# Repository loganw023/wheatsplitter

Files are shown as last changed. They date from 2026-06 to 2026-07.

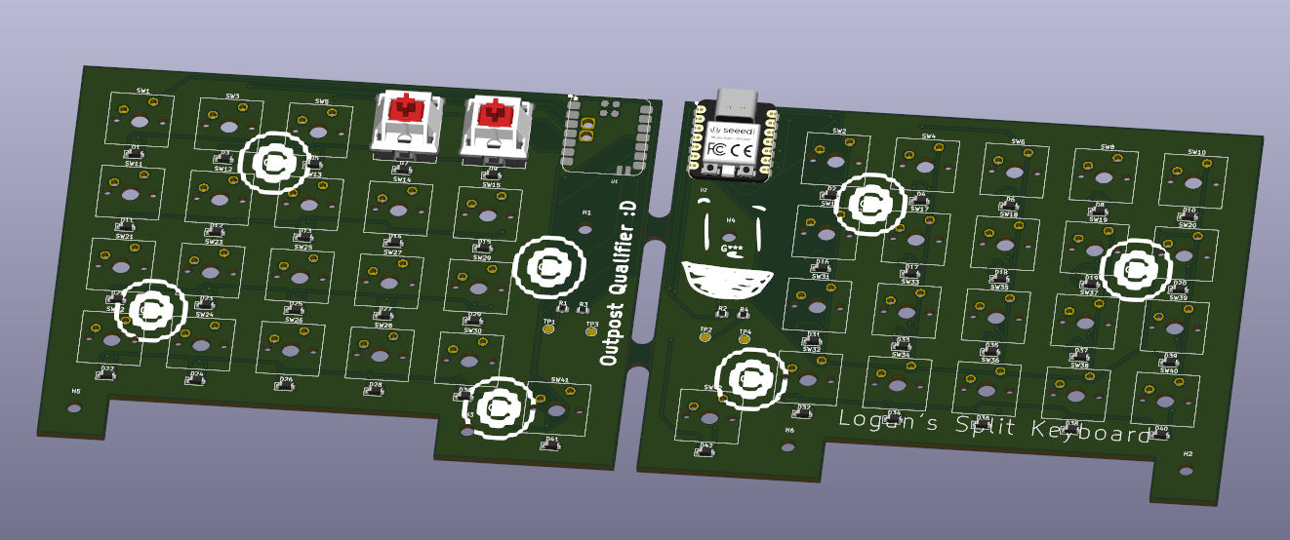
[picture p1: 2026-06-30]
Photos/Screenshot 2026-06-30 133020.png

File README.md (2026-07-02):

# wheatsplitter
This is a custom split ortholinear mechanical keyboard. I built this project to qualify for Outpost and to further my PCB, CAD, and coding skills. I was also interested in building this keyboard because I worked on Hackpad last summer, and wanted to continue building keyboard-type projects. This project taught me a lot about PCB design, especially since my last PCB was done in December. I also learned a lot about the specifics on how keyboard matrixes work, which was very interesting. 

## Schematic
Here is my schematic:


## PCB
Here is the PCB:



## CAD
Here is the CAD for the case:



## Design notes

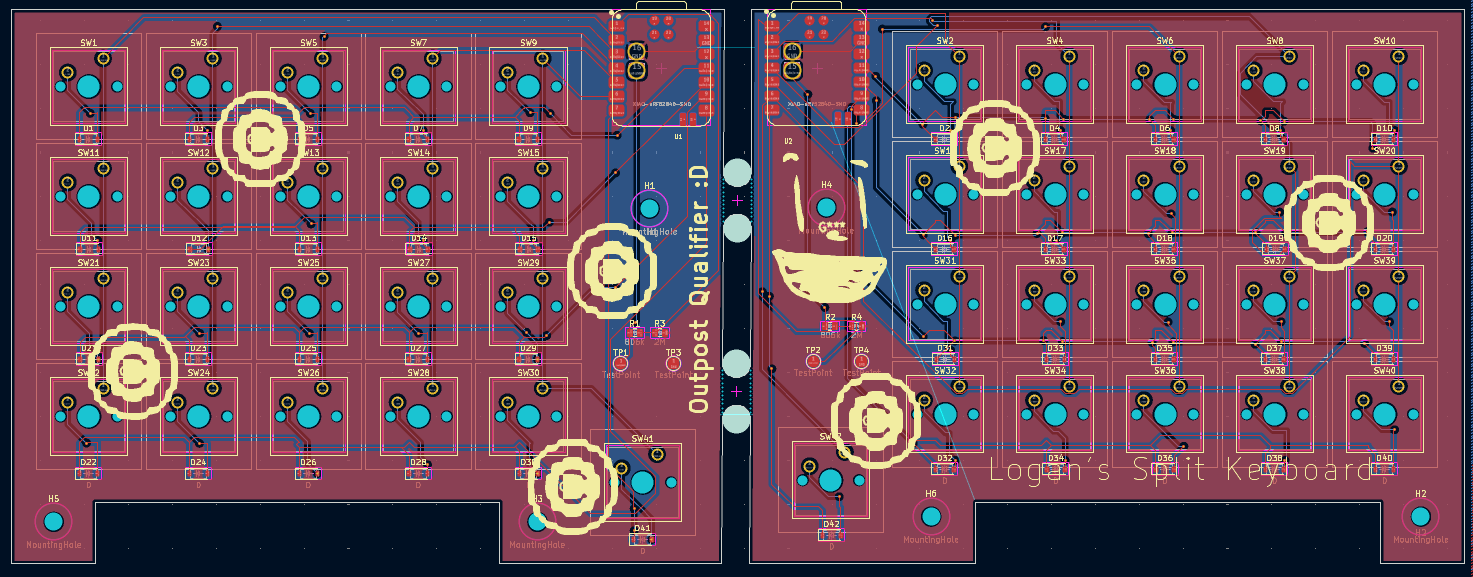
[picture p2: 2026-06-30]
Photos/Screenshot 2026-06-30 150526.png

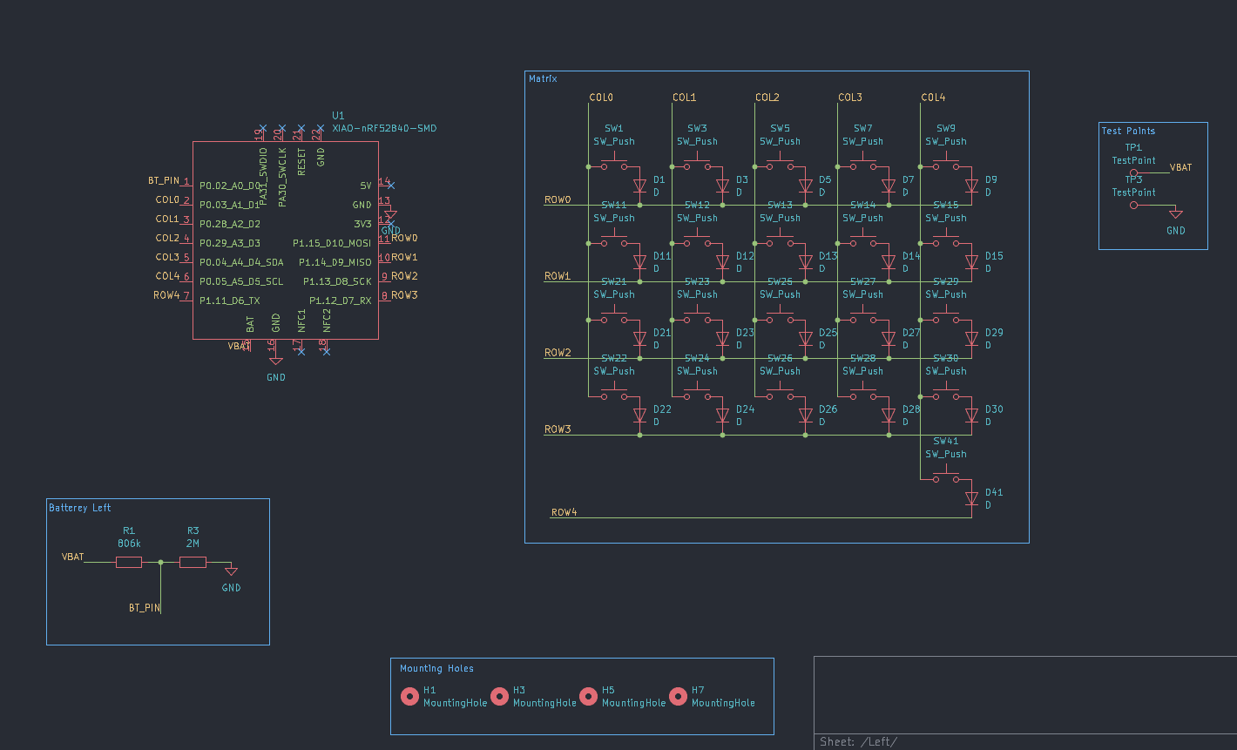
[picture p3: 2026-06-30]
Photos/Screenshot 2026-06-30 150544.png

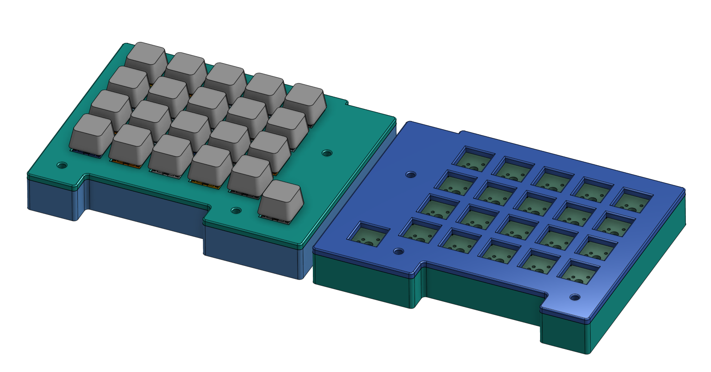
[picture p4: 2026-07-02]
Photos/Screenshot 2026-07-01 172532.png

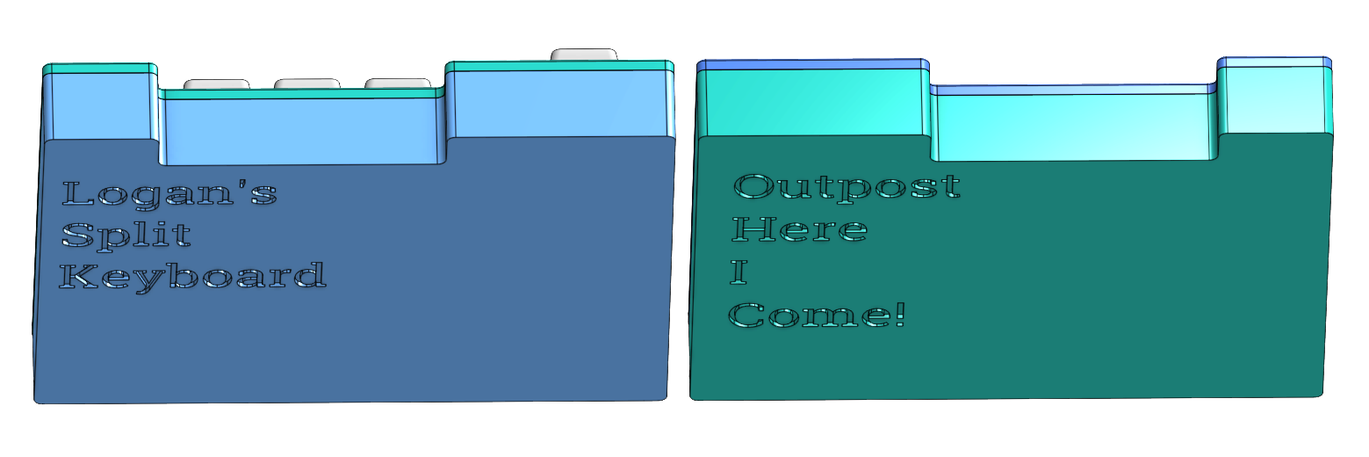
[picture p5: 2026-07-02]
Photos/Screenshot 2026-07-01 172958.png

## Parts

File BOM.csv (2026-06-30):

Item | Quantity | Costs
XIAO NRF52840 | 2
2M Resistors | 2
806k Resistor | 2
Cherry MX Switches | 42
1N4148 Diodes | 42
Test Point Pads | 4
PCB | 5
Case (3D Printed) | 2
Keycaps (3D Printed) | 42
Total Cost |  | 0
Will not be requesting a grant for this project, just ship!

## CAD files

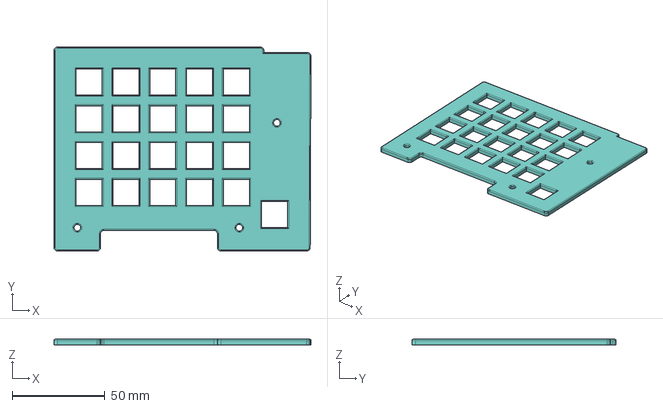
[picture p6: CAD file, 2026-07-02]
CAD/LTop.step
138.5 x 110.0 x 3.00 mm

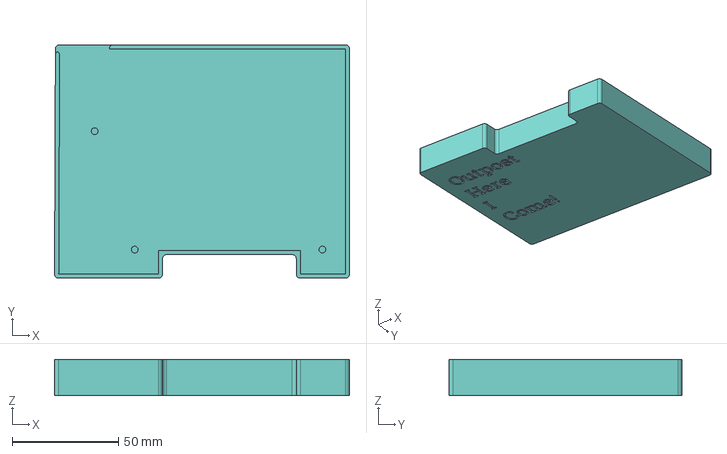
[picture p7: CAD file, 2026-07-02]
CAD/RBottom.step
139.0 x 110.0 x 17.0 mm

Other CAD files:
CAD/RTop.step
CAD/LBottom.step
CAD/LBottom.stl
CAD/LTop.stl
CAD/RBottom.stl
CAD/RTop.stl

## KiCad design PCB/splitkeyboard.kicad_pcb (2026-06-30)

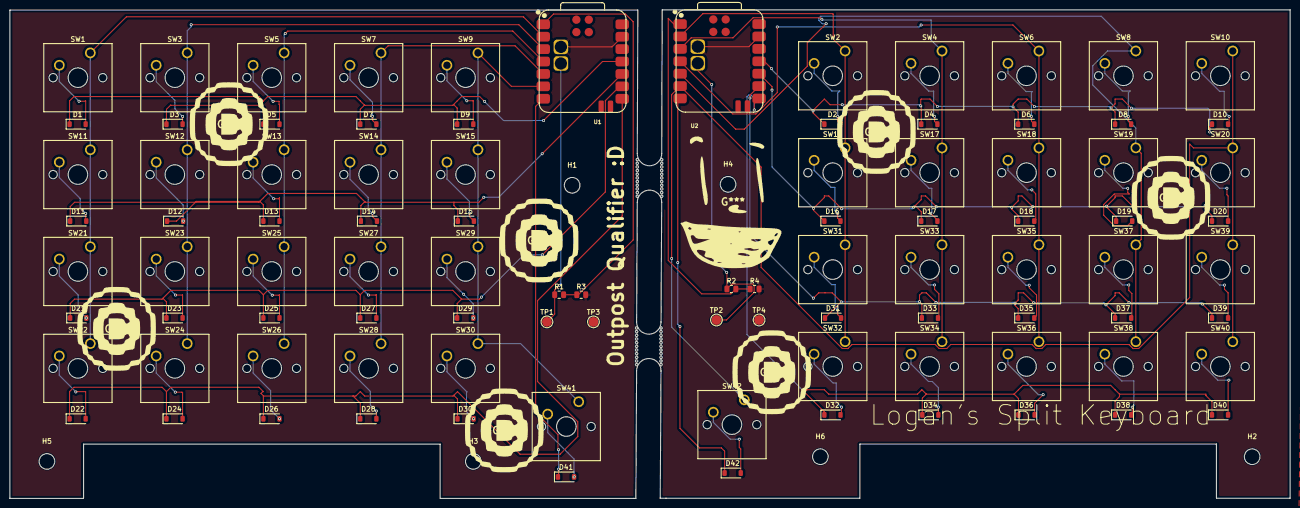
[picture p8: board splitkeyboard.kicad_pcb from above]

Board: 2 copper layers, 262.1 x 100.0 mm, 102 parts (0 on the bottom side), 67 nets.

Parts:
D1, D2, D3, D4, D5, D6, D7, D8, D9, D10, D11, D12, D13, D14, D15, D16, D17, D18, D19, D20, D21, D22, D23, D24, D25, D26, D27, D28, D29, D30, D31, D32, D33, D34, D35, D36, D37, D38, D39, D40, D41, D42: D; D_SOD-123
H1, H2, H3, H4, H5, H6: MountingHole; MountingHole_3.2mm_M3
H4#2, H7: MountingHole; mouse-bite-5mm-slot
R1, R2: 806k; R_0805_2012Metric
R3, R4: 2M; R_0805_2012Metric
SW1, SW2, SW3, SW4, SW5, SW6, SW7, SW8, SW9, SW10, SW11, SW12, SW13, SW14, SW15, SW16, SW17, SW18, SW19, SW20, SW21, SW22, SW23, SW24, SW25, SW26, SW27, SW28, SW29, SW30, SW31, SW32, SW33, SW34, SW35, SW36, SW37, SW38, SW39, SW40, SW41, SW42: SW_Push; SW_Cherry_MX_1.00u_PCB
TP1, TP2, TP3, TP4: TestPoint; TestPoint_Pad_D2.0mm
U1, U2: XIAO-nRF52840-SMD; modified-XIAO-nRF52840-SMD

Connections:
/Left/BT_PIN: R1.2, R3.1, U1.1 (P0.02_A0_D0)
/Left/COL0: SW1.1, SW11.1, SW21.1, SW22.1, U1.2 (P0.03_A1_D1)
/Left/COL1: SW3.1, SW12.1, SW23.1, SW24.1, U1.3 (P0.28_A2_D2)
/Left/COL2: SW5.1, SW13.1, SW25.1, SW26.1, U1.4 (P0.29_A3_D3)
/Left/COL3: SW7.1, SW14.1, SW27.1, SW28.1, U1.5 (P0.04_A4_D4_SDA)
/Left/COL4: SW9.1, SW15.1, SW29.1, SW30.1, SW41.1, U1.6 (P0.05_A5_D5_SCL)
/Left/ROW0: D1.1 (K), D3.1 (K), D5.1 (K), D7.1 (K), D9.1 (K), U1.11 (P1.15_D10_MOSI)
/Left/ROW1: D11.1 (K), D12.1 (K), D13.1 (K), D14.1 (K), D15.1 (K), U1.10 (P1.14_D9_MISO)
/Left/ROW2: D21.1 (K), D23.1 (K), D25.1 (K), D27.1 (K), D29.1 (K), U1.9 (P1.13_D8_SCK)
/Left/ROW3: D22.1 (K), D24.1 (K), D26.1 (K), D28.1 (K), D30.1 (K), U1.8 (P1.12_D7_RX)
/Left/ROW4: D41.1 (K), U1.7 (P1.11_D6_TX)
/Left/VBAT: R1.1, TP1.1, U1.15 (BAT)
/Right/BT_PIN: R2.2, R4.1, U2.1 (P0.02_A0_D0)
/Right/COL0: SW2.1, SW16.1, SW31.1, SW32.1, U2.2 (P0.03_A1_D1)
/Right/COL1: SW4.1, SW17.1, SW33.1, SW34.1, U2.3 (P0.28_A2_D2)
/Right/COL2: SW6.1, SW18.1, SW35.1, SW36.1, U2.4 (P0.29_A3_D3)
/Right/COL3: SW8.1, SW19.1, SW37.1, SW38.1, U2.5 (P0.04_A4_D4_SDA)
/Right/COL4: SW10.1, SW20.1, SW39.1, SW40.1, SW42.1, U2.6 (P0.05_A5_D5_SCL)
/Right/ROW0: D2.1 (K), D4.1 (K), D6.1 (K), D8.1 (K), D10.1 (K), U2.11 (P1.15_D10_MOSI)
/Right/ROW1: D16.1 (K), D17.1 (K), D18.1 (K), D19.1 (K), D20.1 (K), U2.10 (P1.14_D9_MISO)
/Right/ROW2: D31.1 (K), D33.1 (K), D35.1 (K), D37.1 (K), D39.1 (K), U2.9 (P1.13_D8_SCK)
/Right/ROW3: D32.1 (K), D34.1 (K), D36.1 (K), D38.1 (K), D40.1 (K), U2.8 (P1.12_D7_RX)
/Right/ROW4: D42.1 (K), U2.7 (P1.11_D6_TX)
/Right/VBAT: R2.1, TP2.1, U2.15 (BAT)
GND: R3.2, R4.2, TP3.1, TP4.1, U1.13 (GND), U1.16 (GND), U2.13 (GND), U2.16 (GND)
unnamed: D1.2 (A), SW1.2
unnamed: D2.2 (A), SW2.2
unnamed: D3.2 (A), SW3.2
unnamed: D4.2 (A), SW4.2
unnamed: D5.2 (A), SW5.2
unnamed: D6.2 (A), SW6.2
unnamed: D7.2 (A), SW7.2
unnamed: D8.2 (A), SW8.2
unnamed: D9.2 (A), SW9.2
unnamed: D10.2 (A), SW10.2
unnamed: D11.2 (A), SW11.2
unnamed: D12.2 (A), SW12.2
unnamed: D13.2 (A), SW13.2
unnamed: D14.2 (A), SW14.2
unnamed: D15.2 (A), SW15.2
unnamed: D16.2 (A), SW16.2
unnamed: D17.2 (A), SW17.2
unnamed: D18.2 (A), SW18.2
unnamed: D19.2 (A), SW19.2
unnamed: D20.2 (A), SW20.2
unnamed: D21.2 (A), SW21.2
unnamed: D22.2 (A), SW22.2
unnamed: D23.2 (A), SW23.2
unnamed: D24.2 (A), SW24.2
unnamed: D25.2 (A), SW25.2
unnamed: D26.2 (A), SW26.2
unnamed: D27.2 (A), SW27.2
unnamed: D28.2 (A), SW28.2
unnamed: D29.2 (A), SW29.2
unnamed: D30.2 (A), SW30.2
unnamed: D31.2 (A), SW31.2
unnamed: D32.2 (A), SW32.2
unnamed: D33.2 (A), SW33.2
unnamed: D34.2 (A), SW34.2
unnamed: D35.2 (A), SW35.2
unnamed: D36.2 (A), SW36.2
unnamed: D37.2 (A), SW37.2
unnamed: D38.2 (A), SW38.2
unnamed: D39.2 (A), SW39.2
unnamed: D40.2 (A), SW40.2
unnamed: D41.2 (A), SW41.2
unnamed: D42.2 (A), SW42.2

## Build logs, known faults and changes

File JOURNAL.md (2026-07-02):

Total time spent: 14 Hours!

# 6/29/2026 5 PM - Finished the schematic   

_Time spent: 2.0h_  

I started by working on my schematic for my split keyboard. The most important part about the schematic was the switch/diode matrix, where I first watched the keyboard video by Joe Scotto to understand how the matrix works, then made my own matrix. I also included test points for the battery, a battery indicator, and the XIAO-nRF52840. Overall, the schematic went pretty smoothly, though deciding what footprint to use for the switch took a while (since I could not find the marbastlib switch footprints), but I ended up going with Cherry MXs. Here is a picture of the finished schematic. 

# 6/29/2026 10 PM - Finished  PCB layout  

_Time spent: 3.0h_  

I finished placing all the footprints in the PCB and laying everything out manually in a specific manner that I liked. It took a couple tries to get the layout right, but I think the layout is clean and simple, which I like. Now, I move on to routing all the traces! 

Actually... 90 minutes later, I fixed a major issue with the Edge.Cuts layer. Since in the 3D viewer the break down the middle wasn't showing up, I had to fix not only the borders of the two split keyboards, but also spent an hour trying to add/troubleshoot the mousebites. In the end, I had to modify the footprint to be on the Edge.Cuts layer rather than the silkscreen layer. Here is the finished layout of the PCB. 

And here is the 3D view:


# 6/30/2026 11 AM - Finished PCB routing   

_Time spent: 3.0h_  

I finished all the traces on the PCB! Routing through the rows and columns was actually pretty fun. I also added ground fill on the front and back. I had to move all the diodes since the DRC was giving me a courtyard overlap error, but other than that, it was a pretty smooth journey. 


Here is the 3D view:


# 6/30/2026 1 PM - Finished CAD for case, added silkscreen art  

_Time spent: 2.0h_  

So I started by finishing the case for my keyboard using the CAD software Onshape. I started by importing the STEP file for the PCB, and designed the case around that by working first on the outline, then adding holes for the switches. I also made sure to add an opening for the USB port, and customized the shape of the case to my PCB. 



Additionally, I added custom silkscreen art on my PCB through the KiCad Image Converter, here is a photo of the new PCB with art:


# 6/30/2026 3 PM - Finalized the project  

_Time spent: 1.0h_  

I worked on the firmware, which mostly required me to map the XIAO ports to pin values in the code. I also worked on creating my Github repo, which mostly required me to take a plethora of screenshots and write the README. Overall, I am quite happy with this project! :D


# 7/1/2026 3 PM - Fixed CAD  

_Time spent: 2.5h_  

Due to my reviewer saying I should fix the CAD, I did just that! I redesigned the entire case from scratch again, acknowledging the split of the two PCBs through the mousebites. Here is a photo of the new cases made in Onshape:


I also added the keycaps and more switches onto the PCB in Onshape to make the keyboard look more complete.   

# 7/1/2026 5 PM - Refined the CAD  

_Time spent: 0.5h_  

I added filets to all the edges of the case in Onshape to make the case feel more polished, and added engravings on the bottom with personal notes!

Here is a photo of the new design:


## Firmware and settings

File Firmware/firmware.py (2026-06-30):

import board

from kmk.kmk_keyboard import KMKKeyboard
from kmk.keys import KC
from kmk.scanners import DiodeOrientation

keyboard = KMKKeyboard()

keyboard.col_pins = (
    board.D0, board.D1, board.D2, board.D3, board.D4,
)
keyboard.row_pins = (
    board.D10, board.D9, board.D8, board.D7, board.D6,
)
keyboard.diode_orientation = DiodeOrientation.ROW2COL

keyboard.keymap = [
    [
        KC.A,    KC.B,    KC.C,    KC.D,    KC.E,
        KC.F,    KC.G,    KC.H,    KC.I,    KC.J,
        KC.K,    KC.L,    KC.M,    KC.N,    KC.O, 
        KC.P,    KC.Q,    KC.R,    KC.S,    KC.T,
        KC.NO,   KC.NO,   KC.NO,   KC.NO,   KC.SPC,
    ]
]

if __name__ == '__main__':
    keyboard.go(hid_type=HIDModes.NKRO)

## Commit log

2026-06-30 Added all files for project
    [BOM.csv, splitkeyboard - Part 50.stl, splitkeyboard - Part 51.stl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]
2026-06-30 Update BOM
    [BOM.csv]
2026-07-01 Fixed the CAD
    [LBottom.step, LBottom.stl, LTop.step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]
2026-07-02 Refined the CAD
    [LBottom.step, LBottom.stl, LTop.step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]
